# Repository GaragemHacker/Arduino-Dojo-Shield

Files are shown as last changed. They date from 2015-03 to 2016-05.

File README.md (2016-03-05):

## Arduino-Dojo-Shield  
Placa de expansão para dojos com a plataforma [Arduino](http://arduino.cc/).

Youtube- Garagem Hacker: Arduino Dojo Shield (http://www.youtube.com/watch?v=JNOXBXoQbEs)

Clone e inicialização:
```
$ git clone --recursive https://github.com/GaragemHacker/Arduino-Dojo-Shield.git
```

###Rev 00 
- Software: Fritzing 0.9.2
- Padrão UNO Rev 3
- Dispositivos:
 - 1x potenciômetro
 - 2x push button
 - 1x LED RGB
 - 1x display 7 segmentos (shift-register)
 - 1x LDR
 - 2x servo motor
- TO-DO
	- [x] Esquemático
	- [x] PCB
	- [x] Protótipo
	- [x] Teste elétrico
	- [x] Códigos de teste
	- [ ] ~~Produção~~ (descontinuado)

###Rev 01
- Software: Eagle 7.5 + SparkFun Eagle Libraries
- Dispositivos:
 - 1x potenciômetro
 - 3x push button
 - 3x LED difuso
 - 1x LED RGB
 - 1x display 7 segmentos (shift-register)
 - 1x LDR
 - 3x servo motor
- TO-DO
	- [x] Esquemático
	- [ ] PCB
	- [ ] Protótipo
	- [ ] Teste elétrico
	- [ ] Produção
	- [ ] Códigos de teste

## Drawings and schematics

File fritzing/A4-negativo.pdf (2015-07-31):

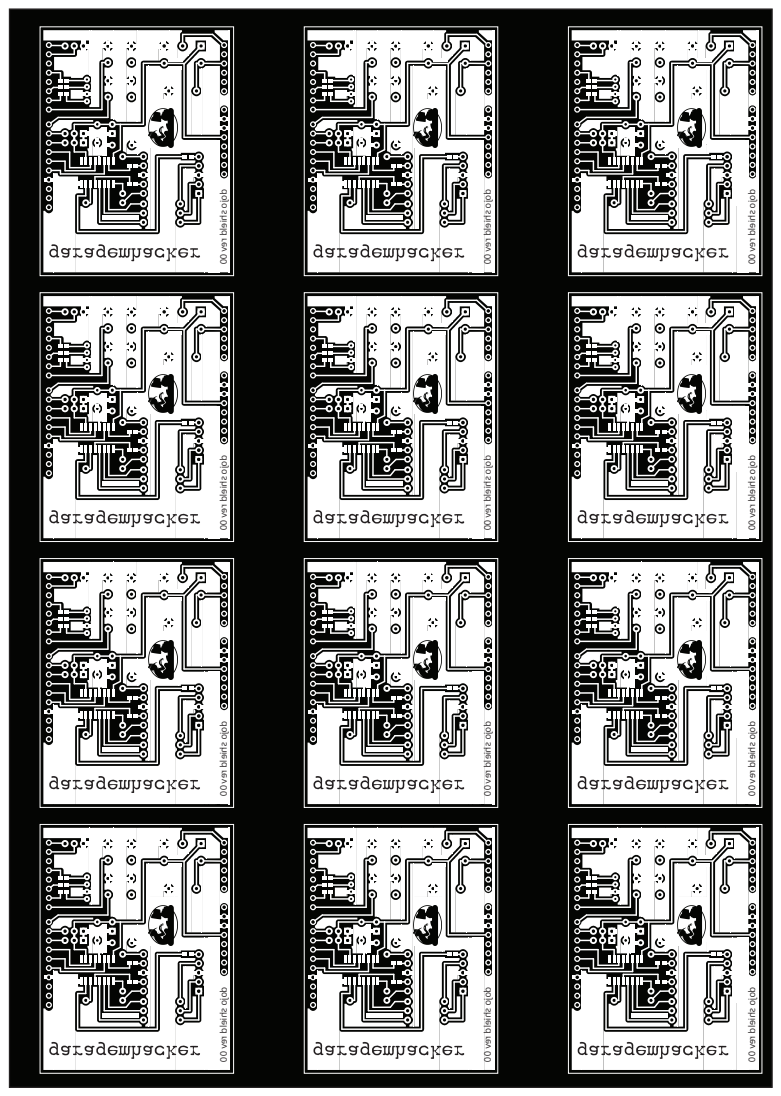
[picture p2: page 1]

dojo shield rev 00 dojo shield rev 00

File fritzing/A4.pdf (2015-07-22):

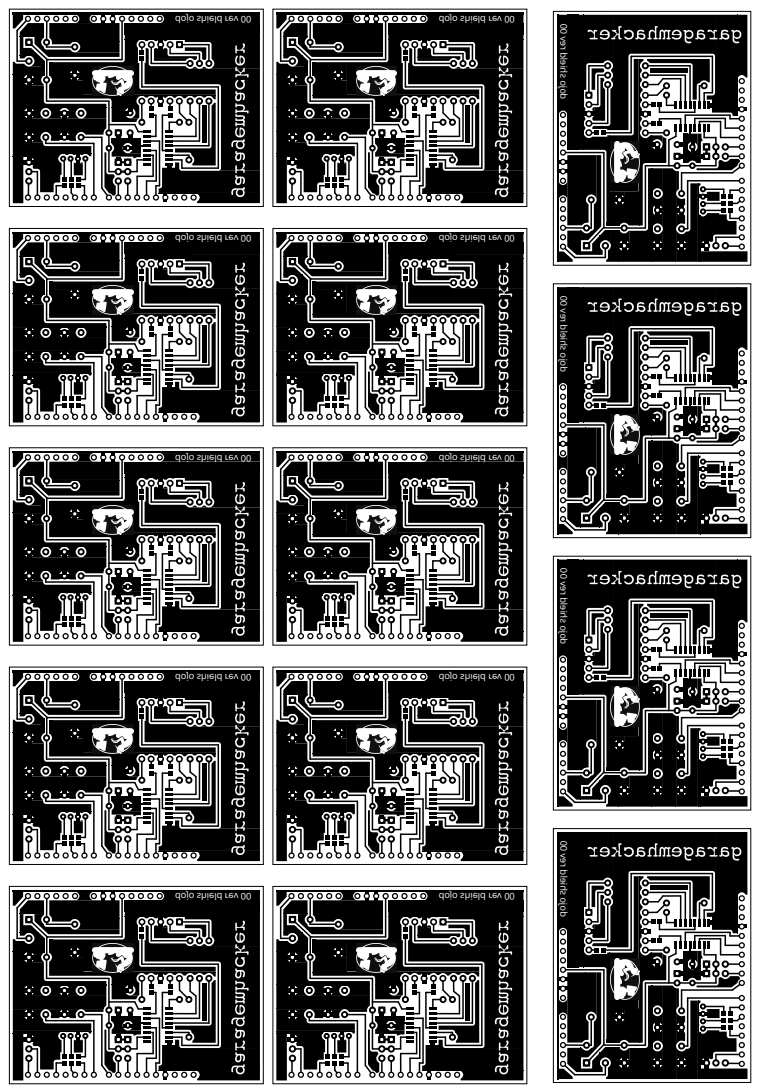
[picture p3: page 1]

dojo shield rev 00

dojo shield rev 00 dojo shield rev 00

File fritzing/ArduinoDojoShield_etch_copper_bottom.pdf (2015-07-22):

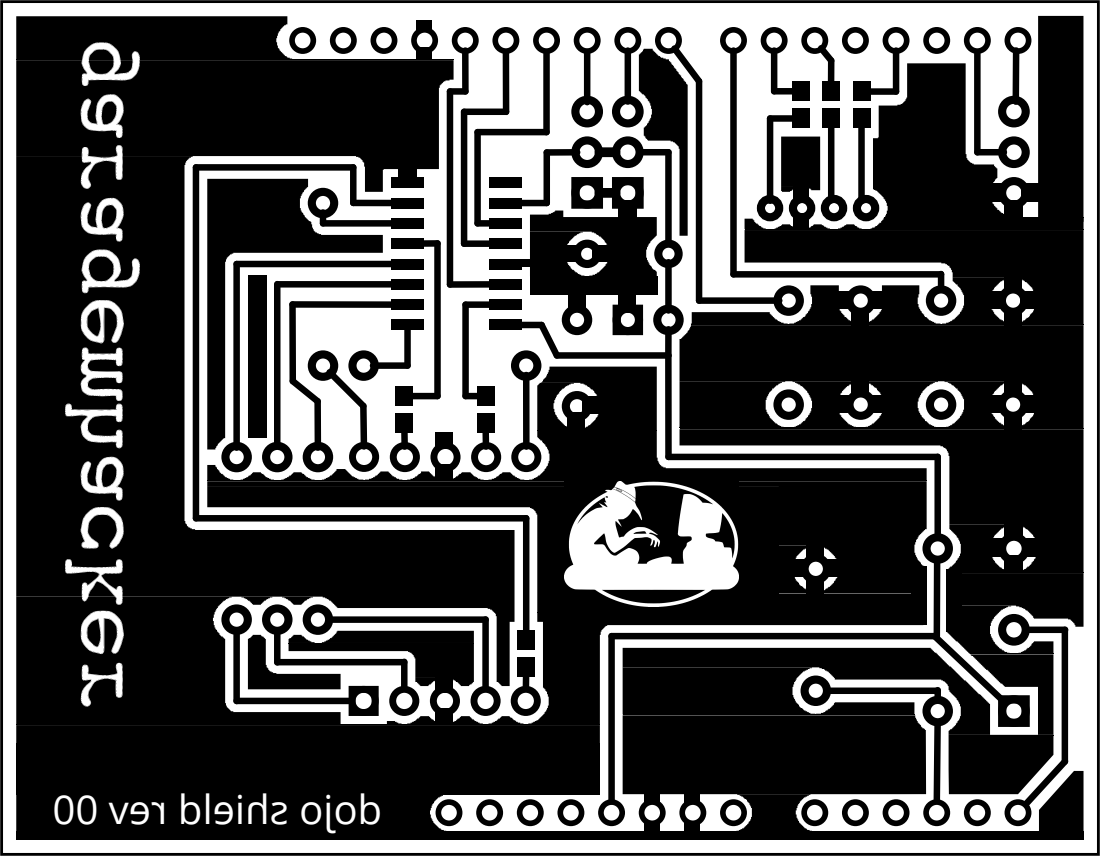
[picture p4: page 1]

dojo shield rev 00

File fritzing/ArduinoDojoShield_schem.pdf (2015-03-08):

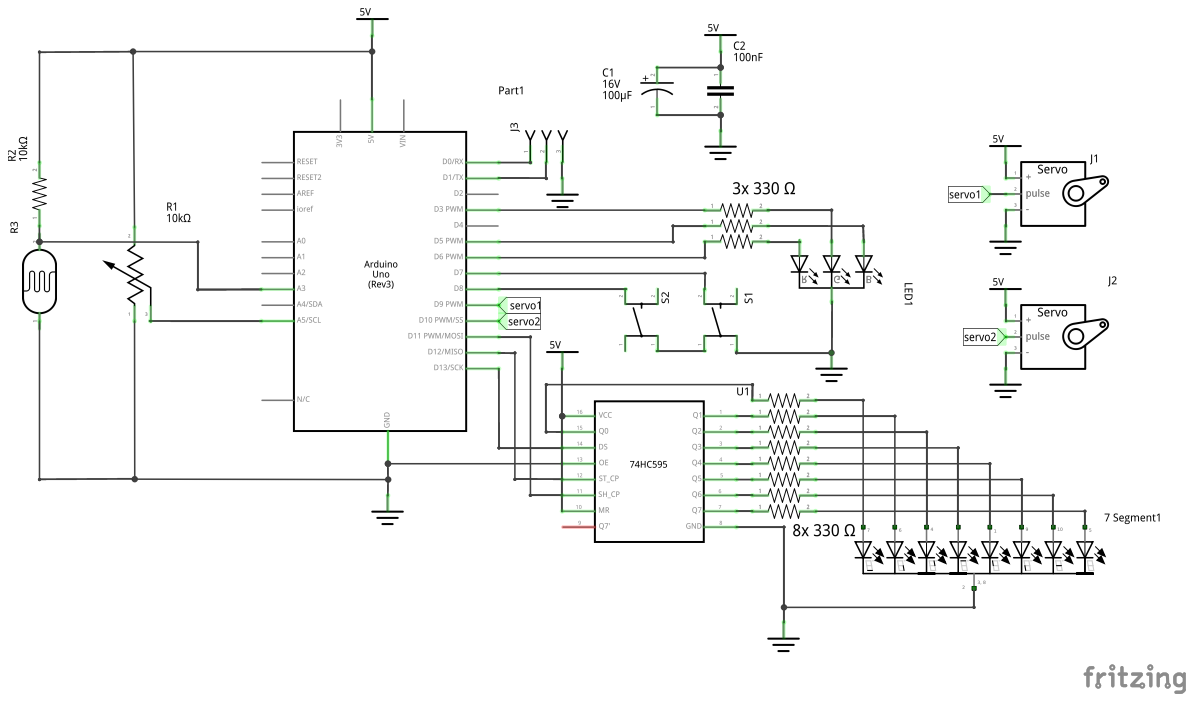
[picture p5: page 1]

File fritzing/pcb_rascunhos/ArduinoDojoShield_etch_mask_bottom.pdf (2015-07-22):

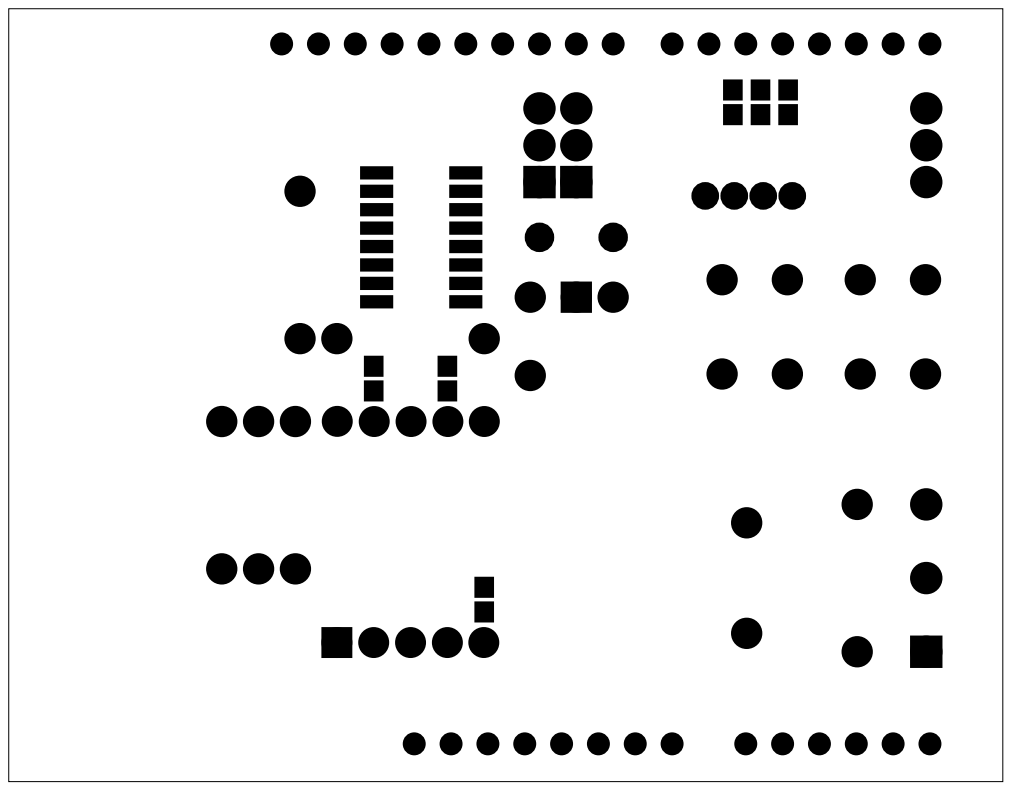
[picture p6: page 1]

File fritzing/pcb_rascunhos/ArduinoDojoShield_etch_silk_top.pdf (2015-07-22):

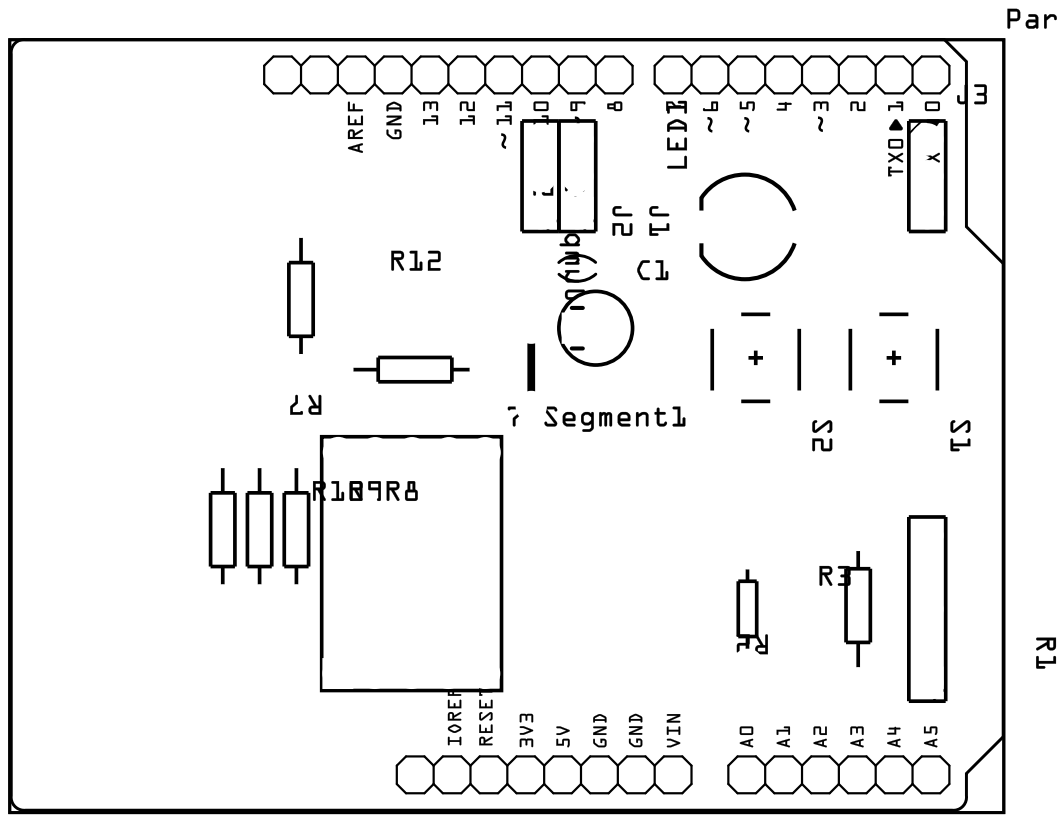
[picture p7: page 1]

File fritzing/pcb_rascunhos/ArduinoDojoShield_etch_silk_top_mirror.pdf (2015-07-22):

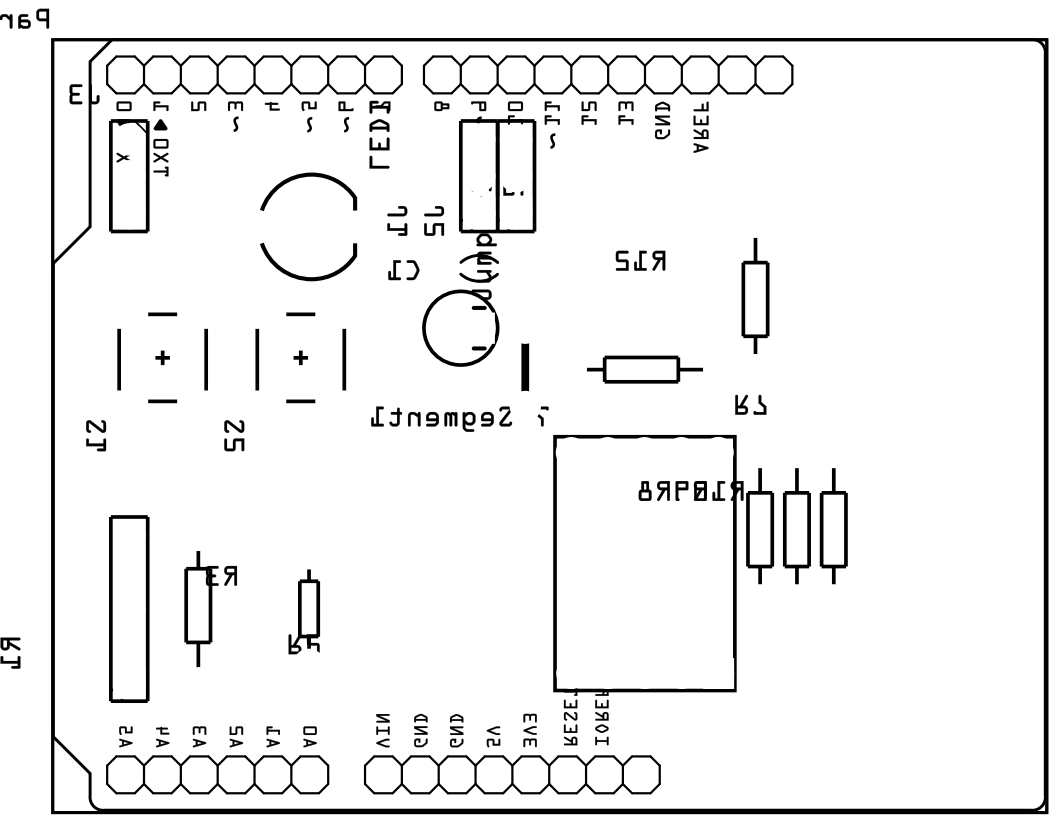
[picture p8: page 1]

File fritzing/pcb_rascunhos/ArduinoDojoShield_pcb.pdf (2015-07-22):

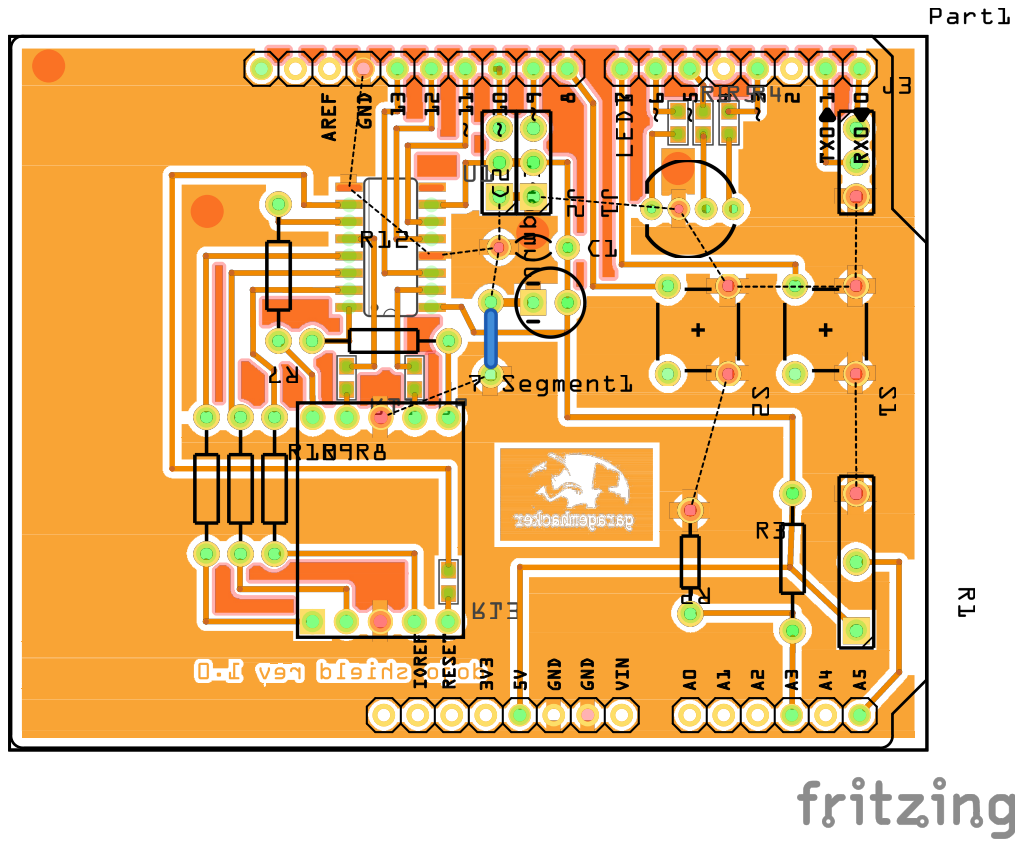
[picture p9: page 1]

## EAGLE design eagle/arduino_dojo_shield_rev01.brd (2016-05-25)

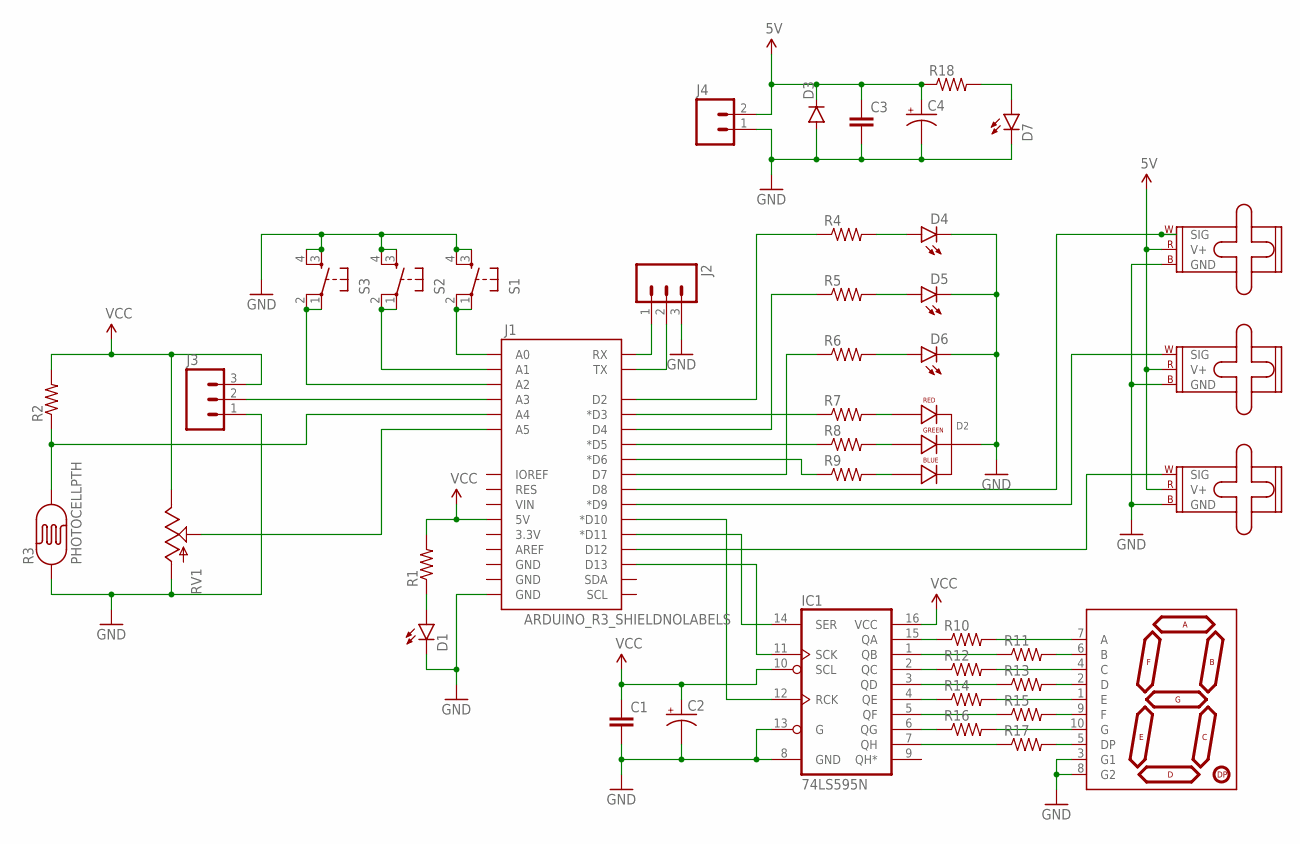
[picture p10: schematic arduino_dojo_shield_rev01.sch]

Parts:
C1, C3: 0.1UF-50V-20%(PTH)KIT-EZ; CAP-PTH-SMALL-KIT
C2, C4: 10UF-25V-20%(PTH); CPOL-RADIAL-10UF-25V
D1, D4, D5, D6, D7: LED3MM
D2: LED-RGB-CC-THRUCLEAR; LED-RGB-THRU
D3: DIODEKIT; DIODE-1N4148-KIT
IC1: 74LS595N; DIL16
J1: ARDUINO_R3_SHIELDNOLABELS; UNO_R3_SHIELD_NOLABELS
J2, J3: M03PTH; 1X03
J4: M025MM; SCREWTERMINAL-5MM-2
M1, M2, M3: SMALL_SERVO; 1X03
R1, R4, R5, R6, R7, R8, R9, R10, R11, R12, R13, R14, R15, R16, R17, R18: RESISTOR0805-RES; 0805
R2: RESISTORPTH-1/4W; AXIAL-0.4
R3: PHOTOCELLPTH; PHOTOCELL
RV1: POT-RV16AF-20; POT_ALPHA_RV16AF-20
S1, S2, S3: TAC_SWITCHPTH; TACTILE-PTH
U$1: 7-SEGMENT-DISPLAYPTH; 7-SEGMENT-DISPLAY

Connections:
5V: C3.1, C4.1 (+), D3.C, J4.2, M1.2 (V+), M2.2 (V+), M3.2 (V+), R18.1
GND: C1.2, C2.2 (-), C3.2, C4.2 (-), D1.K (C), D2.2 (CATHODE), D3.A, D4.K (C), D5.K (C), D6.K (C), D7.K (C), IC1.8 (GND), IC1.13 (G), J1.GND@0 (GND), J2.3, J3.1, J4.1, M1.3 (GND), M2.3 (GND), M3.3 (GND), R3.1, RV1.1 (A), S1.3, S1.4, S2.3, S2.4, S3.3, S3.4, U$1.3 (G1), U$1.8 (G2)
unnamed: J1.A4, R2.P$1 (1), R3.2
unnamed: J1.A3, J3.2
unnamed: IC1.4 (QE), R14.1
unnamed: J1.D6 (*D6), R9.1
unnamed: J1.D5 (*D5), R8.1
unnamed: J1.RX, J2.1
unnamed: J1.TX, J2.2
unnamed: J1.D3 (*D3), R7.1
unnamed: D2.1 (RED_CATHODE), R7.2
unnamed: D2.3 (GREEN_CATHODE), R8.2
unnamed: D2.4 (BLUE_CATHODE), R9.2
unnamed: J1.D7, R6.1
unnamed: IC1.11 (SCK), J1.D13
unnamed: IC1.15 (QA), R10.1
unnamed: R10.2, U$1.7 (A)
unnamed: J1.D12, M2.1 (SIG)
unnamed: J1.D9 (*D9), M1.1 (SIG)
unnamed: IC1.1 (QB), R11.1
unnamed: R11.2, U$1.6 (B)
unnamed: IC1.2 (QC), R12.1
unnamed: R12.2, U$1.4 (C)
unnamed: IC1.3 (QD), R13.1
unnamed: R13.2, U$1.2 (D)
unnamed: IC1.14 (SER), J1.D11 (*D11)
unnamed: R14.2, U$1.1 (E)
unnamed: IC1.5 (QF), R15.1
unnamed: R15.2, U$1.9 (F)
unnamed: IC1.6 (QG), R16.1
unnamed: R16.2, U$1.10 (G)
unnamed: IC1.7 (QH), R17.1
unnamed: R17.2, U$1.5 (DP)
unnamed: J1.D8, M3.1 (SIG)
unnamed: D7.A, R18.2
unnamed: J1.A1, S2.1, S2.2
unnamed: J1.A2, S3.1, S3.2
unnamed: J1.A0, S1.1, S1.2
unnamed: D1.A, R1.1
unnamed: J1.A5, RV1.2 (S)
unnamed: D5.A, R5.2
unnamed: D6.A, R6.2
unnamed: D4.A, R4.2
unnamed: J1.D4, R5.1
unnamed: J1.D2, R4.1
unnamed: IC1.12 (RCK), J1.D10 (*D10)
VCC: C1.1, C2.1 (+), IC1.10 (SCL), IC1.16 (VCC), J1.5V, J3.3, R1.2, R2.P$2 (2), RV1.3 (E)

Board: 2 copper layers, 42 parts (16 on the bottom side), 47 nets, no tracks yet.

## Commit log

2015-03-03 adicionado esquemático - Fritzing
    [ArduinoDojoShield.fzz]
2015-03-08 add v1.0
    [ArduinoDojoShield.fzz]
2015-07-22 Arduino Dojo Shield rev 00
2016-02-11 Rev 01 - schematic
    [arduino_dojo_shield_rev01.brd, arduino_dojo_shield_rev01.sch]
2016-03-05 rev 01 - sem layout
    [arduino_dojo_shield_rev01.brd, arduino_dojo_shield_rev01.sch]
2016-05-25 eagle rev 0
    [arduino_dojo_shield_rev01.brd]

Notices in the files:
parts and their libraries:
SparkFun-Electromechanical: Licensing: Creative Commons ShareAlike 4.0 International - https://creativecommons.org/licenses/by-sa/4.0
